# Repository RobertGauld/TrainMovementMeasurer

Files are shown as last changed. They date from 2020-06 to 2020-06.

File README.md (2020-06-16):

# Train Movement Measurer

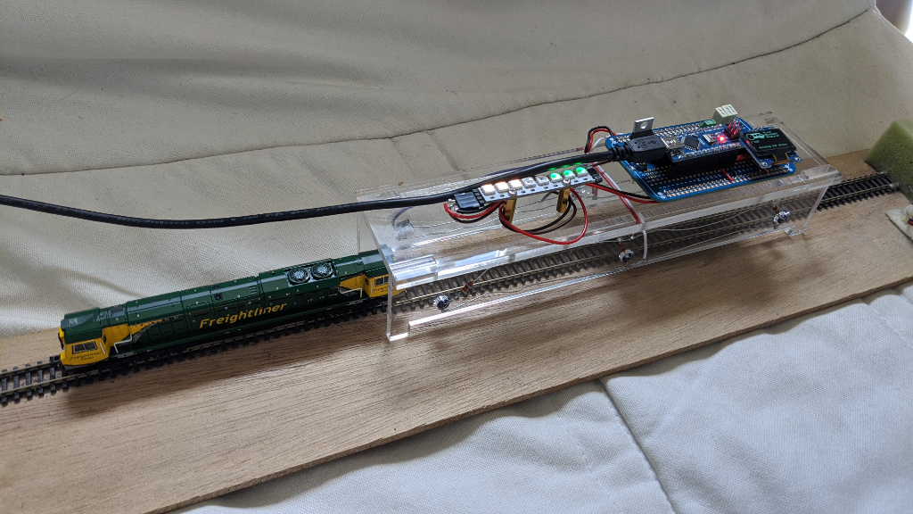
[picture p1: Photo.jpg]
Photo of completed project on my short test track


This is a project to to measure the scale speed and acceleration of a model train moving along a piece of straight track. I hope I've managed to document it such that someone just starting out with their [Arduino](https://www.arduino.cc/) adventure can follow along and create their own. If you're not a beginner you'll likely want to skim through rather than completely read this readme. The timings required can be made either by using three gates (detecting a train being a specific spot) or four blocks (detecting a train being in a specific part of the track). You can choose to only measure speed, in which case you need one less detector.

[Why?](#why)\
[The Physics & Maths](#the-physics-maths)\
[The Electronics & Tunnel](#the-electronics-tunnel)\
[Options](#options)

---

## Why?

By measuring the scale speed of a train you're able to more easily speed match across a fleet of [DCC](https://wikipedia.org/wiki/Digital_Command_Control "Digital Command Control on Wikipedia") equipped locomotives, or learn what a realistic running speed looks like. By also measuring acceleration you're able to automate the speed matching (if you're feeling adventurous) by only paying attention to readings once the train has clearly reached the desired speed step or learn how not to make your passengers spill their coffee.

## The Physics & Maths

We're going to assume that the track is a 20cm long straight length (curves are possible you just need to be careful with measuring how far the train travels between different triggers - the maths is then the same). Physicists normally love simplifying things down to spheres in a vacuum, however for us it's simpler to consider our train to be a solid cube travelling along a straight line (our track). The fact the front of our train isn't exactly a cube doesn't matter as assuming the detectors are all the same then they will be triggered when the same part of the train is at the spot we care about.

As we learnt and school speed is calculated by dividing distance travelled by time taken.\
_s = d ÷ t_\
To keep things simple we'll stick to metric so we end up with a measurement in m/s (meters per second). Since we know the distance between our triggers it's as simple is timing how long elapses between two triggers being triggered.
In the same way as speed measures the rate at which distance changes acceleration measures the rate at which speed changes, since we're working in metric this is in meters per second per second or m/s² (in the following formula Δ represents the change in a value).\
_a = Δs ÷ t_\
At this point we can do some conversions to get from m/s and m/s² into something a bit more meaningful:
* To get Km/h or Km/h/s multiply by 3.6 × scale
* To get mph or mph/s multiply by 2.236936 × scale

Now we now the basics, let's discover how to use three detectors to measure three speeds and one acceleration:\
d₁ is the distance between the first two triggers.\
d₂ is the distance between the last two triggers.\
d is the total distance (_d₁ + d₂_).\
t₁ is the time between the first two triggers.\
t₂ is the time between the last two triggers.\
t is the total time (_t₁ + t₂_).\
s₁ is the speed between the first two triggers.\
s₂ is the speed between the last two triggers.\
s is the speed between the first and last detector.\
a is the acceleration between the first and last  detector.

From the above we can easily calculate our speeds using:\
_s₁ = d₁ ÷ t₁_\
_s₂ = d₂ ÷ t₂_\
_s = d ÷ t_\
From here we have to understand that if the train is accelerating at a constant rate (which we're going to assume it is to keep things simple) then the speeds s₁ and s₂ occur at the times ½t₁ and ½t₂ (that is to say half way through each gap between detectors). We can therefore calculate the speed change and acceleration using:\
_Δs = s₂ - s₁_\
_a = Δs ÷ ½t_



There are two methods of measuring the time, depending on which style of train detection makes the most sense for your use case. I'll only describe the measurements for a train moving left to right but the code can also handle a train running right to left.\
Either we can setup three gates to detect when the train is a particular point of the track. Timer 1 is started when gate 0 is triggered and stopped when gate 1 is triggered. Timer 2 is started when gate 1 in triggered and stopped when gate 2 is triggered.\
Or we can setup four blocks of track to detect when a train is present in them (we only actually care about the length of two of them). Timer 1 is started when track 1 becomes occupied and stopped when track 2 becomes occupied. Timer 2 is started when track 2 is occupied and stopped when track 3 is occupied.
If you're only interested in measuring speed the comments in the code give you various options.

## The Electronics & Tunnel

The electronics are rather simple an Arduino provides the brains whilst an OLED display and NeoPixel LED stick let you know what's going on and how fast you're driving.
There are several options for detecting a train's position for the calculations, these are discussed in [Electronics/README.md](Electronics/README.md).

As you may be able to make out from the photo at the top I opted for using three light gates attached to a platic tunnel. A light gate is simply alight shining accorss the track into a detector, when the beam is broken we knoe the train has arrived at that point.
If you wish to use this method then see  [Tunnel/README.md](Tunnel/README.md).

## The Code

The code provides some test modes which can be used to troubleshoot the hardware, see the comments in the code for further details. The code may need some changes before you compile and upload it to the Arduino, follow the comments in the code file.

If you've built this exactly as I did you should only need to change one line (which tells the Arduino what scale to use). If you've kept the electronics the same but changed how far apart the light gates are you'll need to make 2 more changes. There are some other things you can tweak in the code such as how long the results are displayed on the screen for. Depending on your display you may need to make some more changes (probably the I2C address). You can also easily change the number of LEDs in the strip should for example you want to use a semi circle or longer stick with more LEDs - in which case you'll want to change the list of colours and what speeds they light for the LEDs.

The code goes through a number of steps when the Arduino receives power:
1. **Setup** - The Arduino gets itself and he screen up and going.
2. **Check** - That the sensors are clear, if not you'll get an error and the display and LEDs will be used to show you which sensors are clear/blocked.
3. **Wait for and time a train**:
    - Using gates:
       1. Wait for the light gate at either end to be blocked - We save when this happened, since we know what direction the train is travelling in we keep track of what the exiting light gate will be too. The LEDs are used to show the direction of travel and that the first time has been saved. The display is updated to show that a train is being timed.
       2. Wait for the middle light gate to be blocked - We save when this happened. The LEDs are used to show that this time has been saved. Skipped if measuring speed only.
       3. Wait for the final light gate to be blocked - We save when this happened. The LEDs are used to show that this time has been saved. We now have gathered all the data we need.
   - Using track occupancy:
       1. Wait for track 1 or 2 to become occupied - We save when this happened, since we now know the direction the train is travelling in we keep track of what the next and final track section will be (either [2 then 3] or [1 then 0]). The LEDs are used to show thw direction of travel and that the first time has been saved. The display is updated to show that a train is being timed.
       2. Wait for the other of track 1 or 2 to become occupied - We save when this happened. The LEDs are used to show that this time has been saved. Skipped if measuring speed only.
       3. Wait for either track 0 or 3 (as appropriate for the train's direction) to become occupied - We save when this happened. The LEDs are used to show that this time has been saved. We now have gathered all the data we need.
4. **Calculate** - We now use the time differences to calculate two speeds and an acceleration (or just the speed). These are then scaled and displayed on the display. The LEDs now show a bar of varying colours - the more LEDs the faster the scale speed. All the calculated values are output to the serial port too (see [SERIAL_PORT.md](SERIAL_PORT.md)).
5. **Wait** - After the configurable time delay (defaults to 15 seconds) we start checking that the train is completly left the area we're watching, when it has we go back to step 2.

## Options

### Gates Without the Light Beam

The only function which the light gates serve is to detect when the train is at specific spots on the track. This could alternativly be achieved in a number of different ways e.g. a button operated by a person or the train's wheels. You will need to make your own adjustments to the circuitry (see [Electronics/LightGates.md](Electronics/LightGates.md)). In addition you'll need to make the following changes in the code:
* Make sure that you configure TRIGGER_PINS to contain the Arduino pins connected to your detectors
* Remove/comment the "#define GATE_LED_PIN" line
* Ensure you set TRIGGER_DETECT correctly

### Track Occupancy Detection

There are a number of ways in which block detection work on a model railway, as such the interfacing between this project and the many available systems will vary. For this reason the electronics are left to the user to design (see [Electronics/Blocks.md](Electronics/Blocks.md)). In addition you'll need to make the following changes in the code:
* Make sure that you configure TRIGGER_PINS to contain the Arduino pins connected to your detectors
* Remove/comment the "#define GATE_LED_PIN" line
* Ensure you set TRIGGER_DETECT correctly
* Make sure that "#define TRIGGER_BLOCKS" is present

### Measure Speed Only

With the current code this is easily achieved by:
* Changing "#undef VELOCITY_ONLY" to "#define VELOCITY_ONLY"
* Making sure your detectors are numbered as the comments in the code describe

### Change the Logo

See [Logos/README.md](Logos/README.md).

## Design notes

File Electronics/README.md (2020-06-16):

# Train Movement Measurer - The Electronics

The heart of the project is an Arduino Nano where our code runs, this can be powered by the onboard USB or through the screw terminal which connects to the Arduino's Vin (accepting 7-12V DC, this circuit requires upto 500mA). It uses an OLED display (connected using I2C) and an optional strip of WS2812 LEDs for output (connected to wires soldered to the breadboard).

There are a number of options for detecting trains:
- [Light Gates](LightGates.md) - Three IR LEDs shine accross the track into three IR detectors. When the train breaks the beam we know it's at that spot. The third can be omitted if you're only measuring speed.
- [Gates](Gates.md) - Three detectors allow us to know when a train is at speific spots on the track. The third can be omitted if you're only measuring speed.
- [Block Occupancy](Blocks.md) - Four sections of track are fitted with train on track detectors. When the train enters/leaves each block we know how far it travelled.

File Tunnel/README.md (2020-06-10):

# Train Movement Measurer - The Tunnel

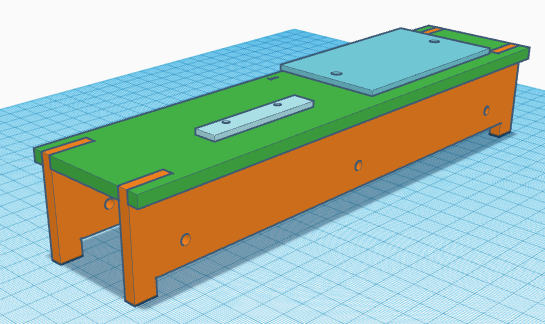
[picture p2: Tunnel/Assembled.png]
Assembled


To hold the light gates a fixed distance apart I had some acrylic LASER cut, in order to make sure it fit together first time I actually used some 3D printing CAD software to create the parts. As a result you have the option of using either of these as a starting point for your tunnel.
The tunnel is designed to take threaded inserts to hold the stand-offs for the breadboard and LED strip. It's also designed with rectangular holes to allow for the routing of wire. In my first build these proved tight but manageable so you may want to increase their length.
All that matters is that the LED and detector of each light gate are in a straight line from each other (preferably horizontal and perpendicular to the track) and are a known fixed distance apart. You could for example choose to have the detectors and circuitry hidden in a station waiting room and the LEDs disguised as relay cabinets should you wish.

## LASER Cutting

I'd previously used [RazorLAB](https://www.razorlab.online/) for some LASER cutting so took their template (no longer available) and added in the parts - [LASER.svg](LASER.svg).
It should be noted that they cut from standard sizes of acrylic and this design uses the middle size (with wastage). It could be shrunk to a shorter tunnel in exchange for fitting on a smaller size and saving money at the loss of accuracy. I've not done that maths but suspect for smaller than OO 5cm (rather than 10cm) spacing of the light gates would suffice. Alternatively the dead space could be used for another project or the experiment this this technology. The slots are designed so that it will fit together when cut from 5mm thick material, you could shrink to using 3mm thickness but would end up with the LEDs protruding more on the inside so watch your clearance.
You should also note that they've been designed for n gauge, for a different scale you'll likely want to change the height of the sides and width of the top to ensure appropriate clearance for your trains.
You should also ensure that the holes are the right size for your threaded inserts and spacing for your breadboard and LED strip.

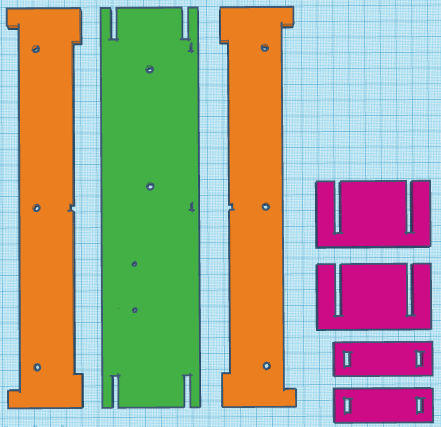
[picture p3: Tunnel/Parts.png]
Parts


The tunnel is designed in 3 parts (well 2 with one duplicated) and some parts to help keep it square during construction (in purple).
The green top is designed to hold the breadboard, LED stick and keep the sides in place. It has holes for threaded inserts and for wires to pass through.
The orange sides are identical and have two large notches at the top for aligning with the top, a large cut-out along the bottom to allow them to straddle point work, circular holes for LEDs/detectors and a rectangular hole for the routing of wires.

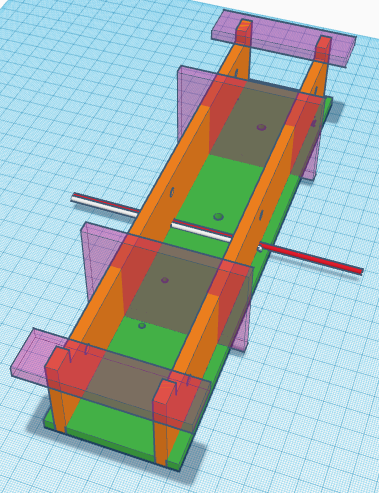
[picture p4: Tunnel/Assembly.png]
Assembly


As can be seen the purple supports will hold the sides square whilst the sides are glued to the top. The holes for the wire are quite tight so it's best to route two wires before glueing.
1. Insert the threaded inserts into the top.
2. Press the sides and top together, ensuring correct orientation.
3. Route the two wires:
    * White (colour doesn't actually matter but I'll be referring to it as white in [the electronics readme](../Electronics/README.md)) from the top, through the side, along the top inside the tunnel and out the other side.
    * Red (colour doesn't actually matter but I'll be referring to it as red in [the electronics readme](../Electronics/README.md)) from one side to the other.
4. Apply glue to the joints between the sides and top, ensuring not to accidentally glue the wires or purple supports.
5. Once the glue has sufficiently set remove the purple supports and glue and bits you had to skip over.

## 3D Printing

As mentioned above this STL file is a by-product of how I designed and test fitted the parts for LASER cutting and as such should be used at your risk.

I'm aware that the parts are larger than a typical build space it could be shrunk to a shorter tunnel in exchange for fitting on a smaller size and saving money at the loss of accuracy. I've not done that maths but suspect for smaller than OO 5cm (rather than 10cm) spacing of the light gates would suffice.
You should also note that they've been designed for n gauge, for a different scale you'll likely want to change the height of the sides and width of the top to ensure appropriate clearance for your trains.
You should also ensure that the holes are the right size for your threaded inserts and spacing for your breadboard and LED strip.

I encourage a contribution from anyone who'd like to take this STL and make a decent version for inclusion here.
[Print.stl](Print.stl)

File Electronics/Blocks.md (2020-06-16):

# Train Movement Measurer - The Electronics (Block Variation)

The heart of the project is an Arduino Nano where our code runs, this can be powered by the onboard USB or through the screw terminal (J4) which connects to the Arduino's Vin (accepting 7-12V DC, this circuit requires upto 500mA). It uses an OLED display (connected using I2C to J1) and an optional strip of WS2812 LEDs for output (connected to wires soldered to the breadboard, J3 in the schematic).

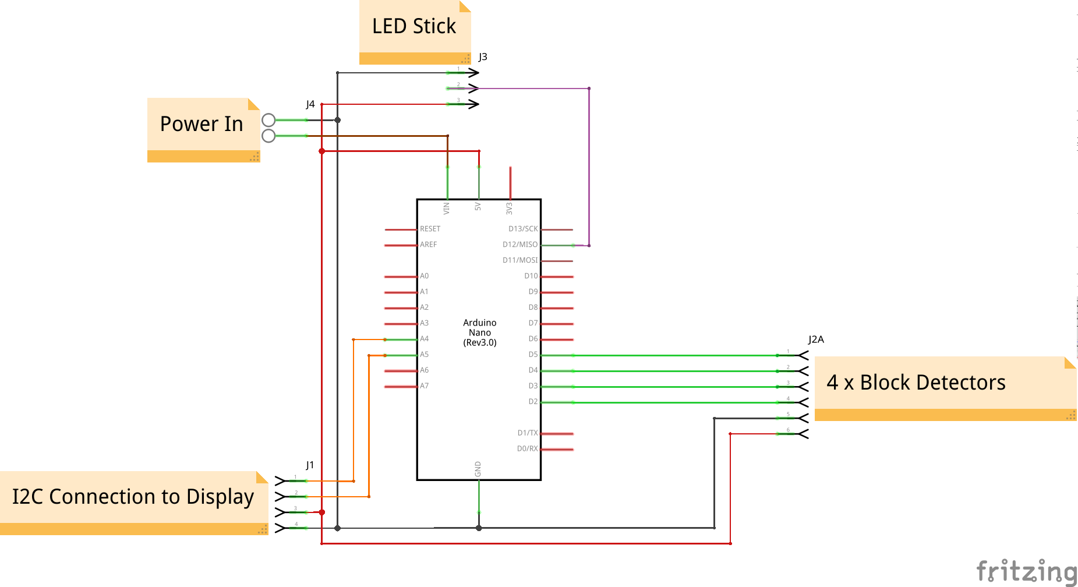
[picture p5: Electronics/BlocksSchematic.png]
Circuit Schematic


Input for timing trains comes from four block occupancy detectors which detect when a train is in a section of the track. Since the interfacing electronics is dependent on your detection method you'll need to design this part for yourself. Try to keep to using Arduino pins 6-2 for blocks 0-4.

## Parts List

* 1 x Half size solderable breadboard
* 1 x Arduino Nano
* 2 x 15x1 Female PCB headers (for Arduino Nano)
* 1 x 4x1 Female PCB header (for display)
* 1 x I2C OLED 128x64 or 128x32
* 1 x NeoPixel Stick (or other shape, at least 8 LEDs)
* 1 x 2 way 2.54mm screw terminal (if external power required)

## Assembly

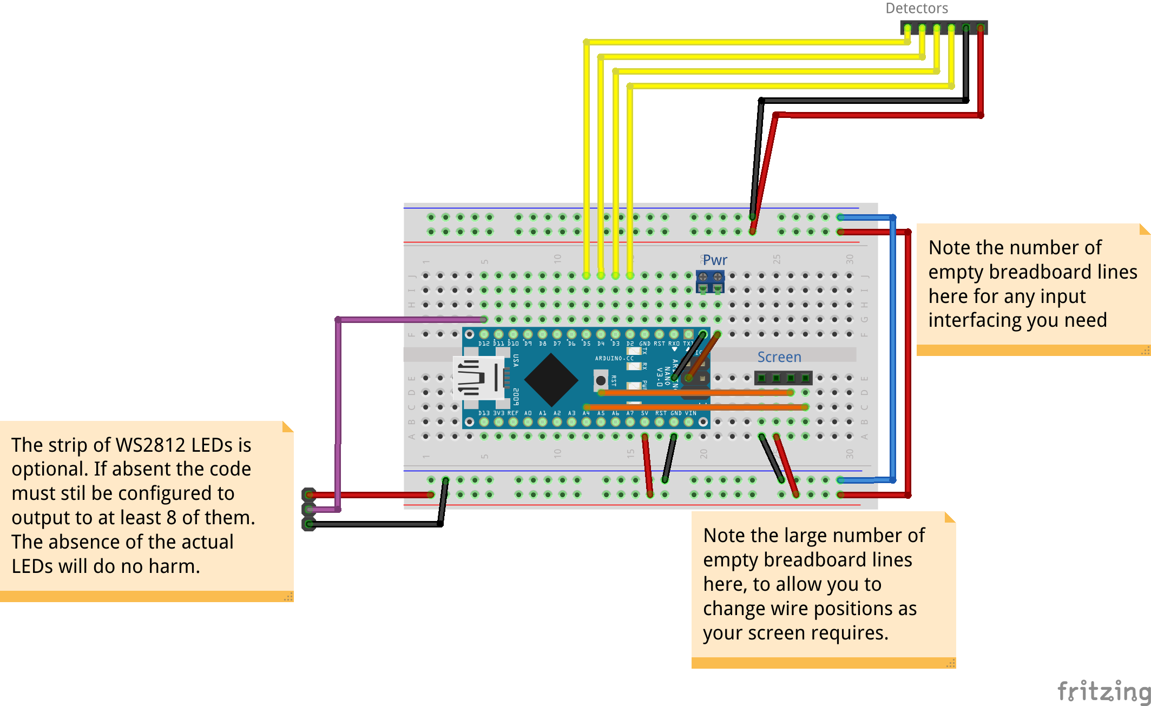
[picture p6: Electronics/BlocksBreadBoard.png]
Breadboard Layout


As always with assembling electronics it's best to go in height order (shortest components to tallest). Note that the wires on the Arduino are actually wired underneath, their just shown there to make where to put them visible. When attaching the headers solder only one pin first then make sure it's sitting square to the board before soldering the rest.

### The breadboard

Start by aligning your solder breadboard as shown by the main board (A1 bottom left and J30 top right).
1. Solder wires between the following pairs of holes:
    * Both blue rails
    * Both red rails
    * A16 - Red rail
    * A18 - Blue rail
    * J4 - Blue rail
    * If you're fitting the power connector:
      * E18 - F20
      * E19 - F21
    * For the screen (note you may need to adjust these based on your screen's size and pinout):
      * C12 - C27
      * D13 - D26
      * A24 - Blue rail
      * A25 - Red rail
2. Solder the screw terminal (if fitting the power connector) to I20-I21
3. Solder the 4x1 header for the screen
4. Solder the 15x1 headers to B5-B19 and F5-F19

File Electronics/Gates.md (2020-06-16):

# Train Movement Measurer - The Electronics (Gate Variation)

The heart of the project is an Arduino Nano where our code runs, this can be powered by the onboard USB or through the screw terminal (J4) which connects to the Arduino's Vin (accepting 7-12V DC, this circuit requires upto 500mA). It uses an OLED display (connected using I2C to J1) and an optional strip of WS2812 LEDs for output (connected to wires soldered to the breadboard, J3 in the schematic).

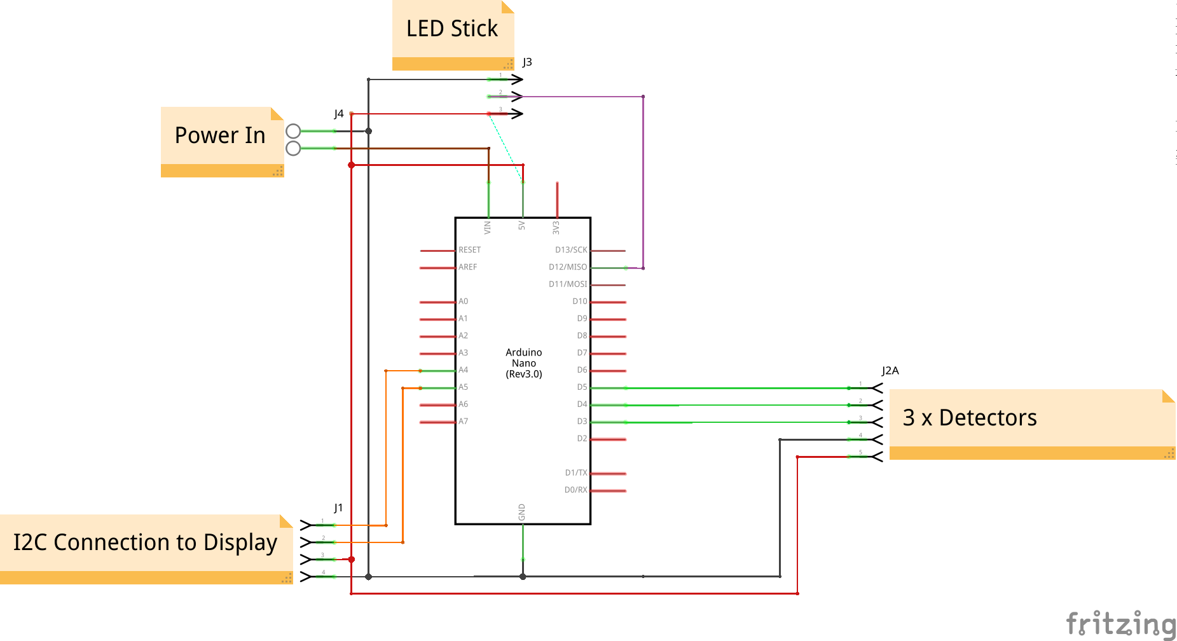
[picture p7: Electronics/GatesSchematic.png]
Circuit Schematic


Input for timing trains comes from three gates which are triggered when the train is at a specific spot of the track. Since the interfacing electronics is dependent on your detection method you'll need to design this part for yourself. Try to keep to using Arduino pins 5-3 for gates 0-2.

## Parts List

* 1 x Half size solderable breadboard
* 1 x Arduino Nano
* 2 x 15x1 Female PCB headers (for Arduino Nano)
* 1 x 4x1 Female PCB header (for display)
* 1 x I2C OLED 128x64 or 128x32
* 1 x NeoPixel Stick (or other shape, at least 8 LEDs)
* 1 x 2 way 2.54mm screw terminal (if external power required)

## Assembly

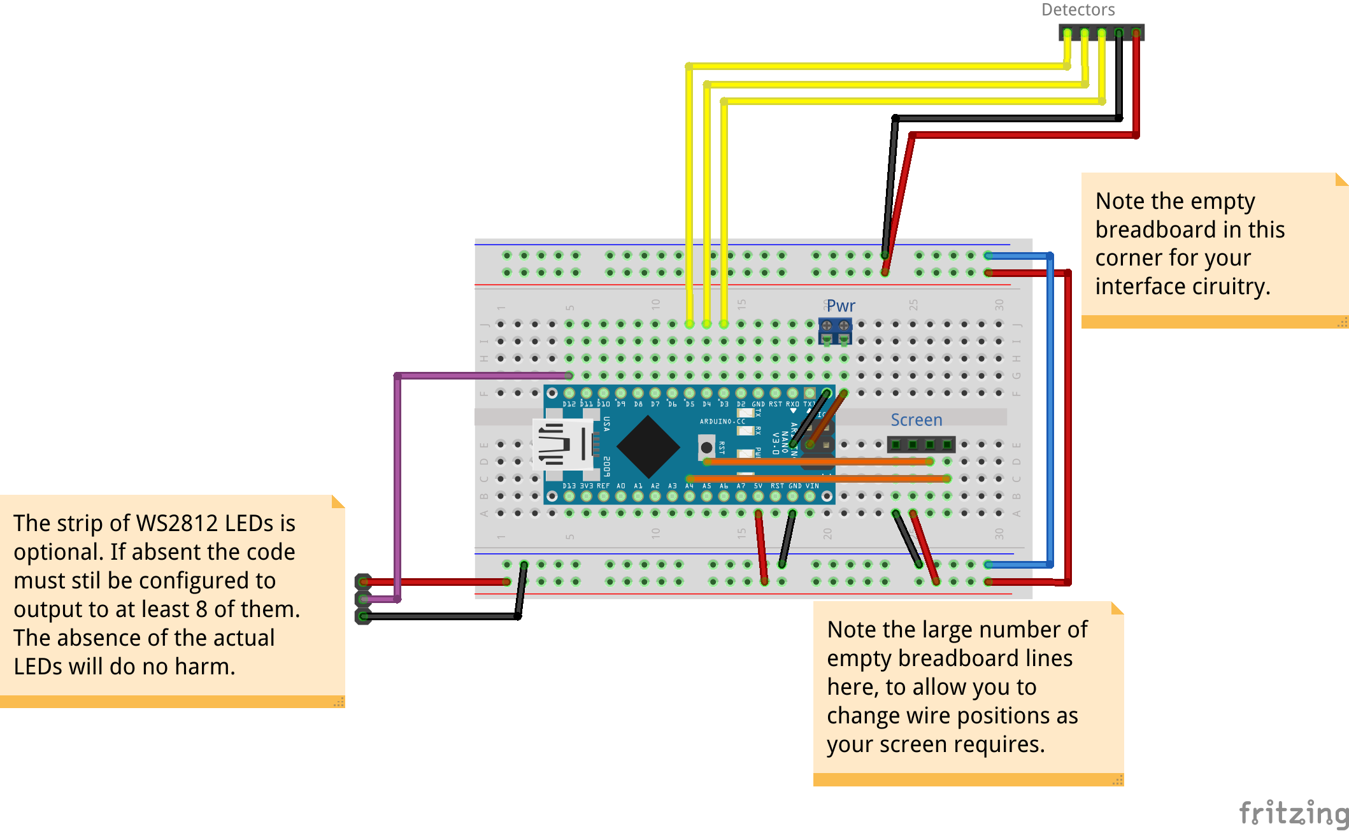
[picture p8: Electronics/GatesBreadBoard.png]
Breadboard Layout


As always with assembling electronics it's best to go in height order (shortest components to tallest). Note that the wires on the Arduino are actually wired underneath, their just shown there to make where to put them visible. When attaching the headers solder only one pin first then make sure it's sitting square to the board before soldering the rest.

### The breadboard

Start by aligning your solder breadboard as shown by the main board (A1 bottom left and J30 top right).
1. Solder wires between the following pairs of holes:
    * Both blue rails
    * Both red rails
    * A16 - Red rail
    * A18 - Blue rail
    * J4 - Blue rail
    * If you're fitting the power connector:
      * E18 - F20
      * E19 - F21
    * For the screen (note you may need to adjust these based on your screen's size and pinout):
      * C12 - C27
      * D13 - D26
      * A24 - Blue rail
      * A25 - Red rail
2. Solder the screw terminal (if fitting the power connector) to I20-I21
3. Solder the 4x1 header for the screen
4. Solder the 15x1 headers to B5-B19 and F5-F19

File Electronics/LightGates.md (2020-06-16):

# Train Movement Measurer - The Electronics (Light Gate Variation)

The heart of the project is an Arduino Nano where our code runs, this can be powered by the onboard USB or through the screw terminal (J4) which connects to the Arduino's Vin (accepting 7-12V DC, this circuit requires upto 500mA). It uses an OLED display (connected using I2C to J1) and an optional strip of WS2812 LEDs for output (connected to wires soldered to the breadboard, J3 in the schematic).

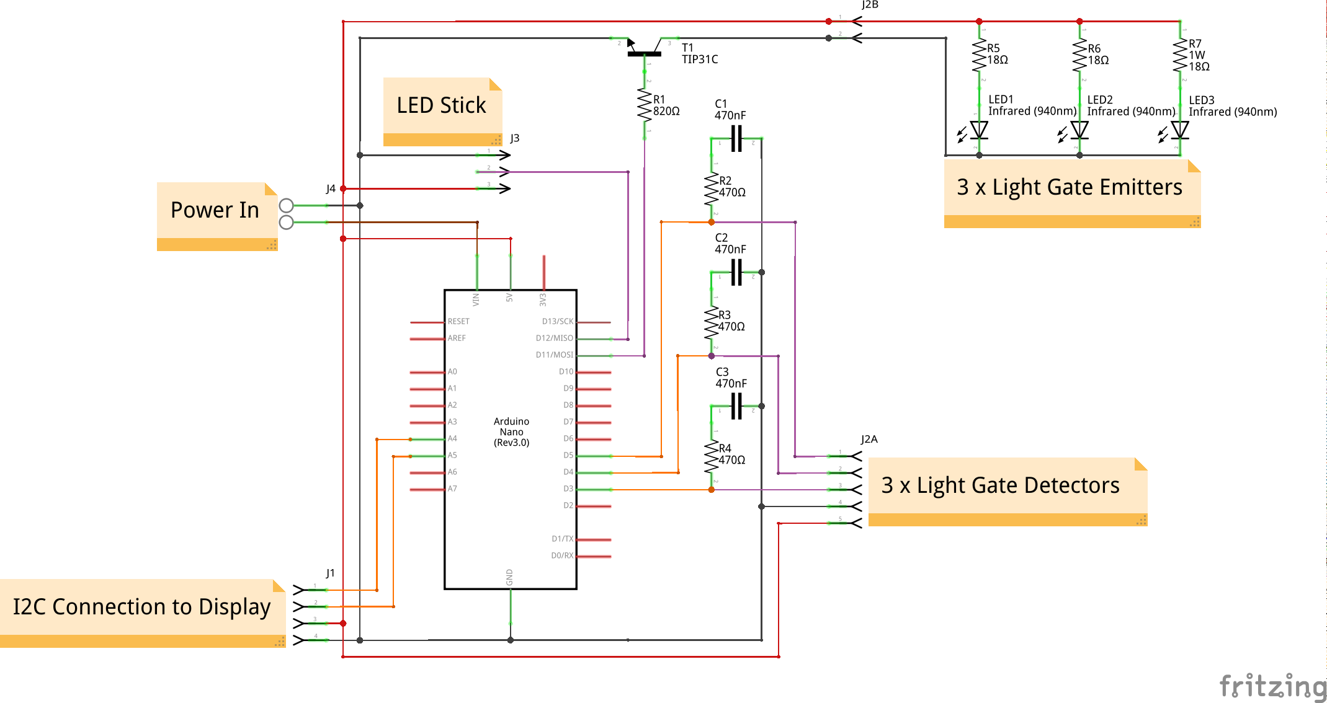
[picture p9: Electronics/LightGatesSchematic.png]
Circuit Schematic


Input for timing trains comes from three light gates using the IR LEDs and detectors. The LEDs are controlled via a transistor to allow them to be flashed at 38KHz. The detectors are connected to the Arduino via a simple RC filter to smooth out the occasional erroneous low reading.
The RC filters work by charging the capacitor whilst the detector's output is high, when the output goes low the capacitor discharges through the resistor keeping the signal to the Arduino high for around 0.15ms. Whilst this does introduce a delay in detection since it's the same delay at each gate and it's the difference we're interested in the delay doesn't matter for our purpose.

## Parts List

* 1 x Half size solderable breadboard
* 1 x Arduino Nano
* 2 x 15x1 Female PCB headers (for Arduino Nano)
* 1 x 4x1 Female PCB header (for display)
* 1 x I2C OLED 128x64 or 128x32
* 1 x NeoPixel Stick (or other shape, at least 8 LEDs)
* 1 x TIP31C NPN transistor (T1)
* 1 x 820Ω 0.6W resistor (R1)
* 3 x 18Ω 1W resistor (R5, R6, R7)
* 3 x 950nm IR LED (TSUS5202)
* 3 x 470Ω 0.6W resistor (R2, R3, R4)
* 3 X 470nF capacitor (C1, C2, C3)
* 3 x TSSP4038 IR receiver
* 1 x 2 way 2.54mm screw terminal (if external power required)

## Assembly

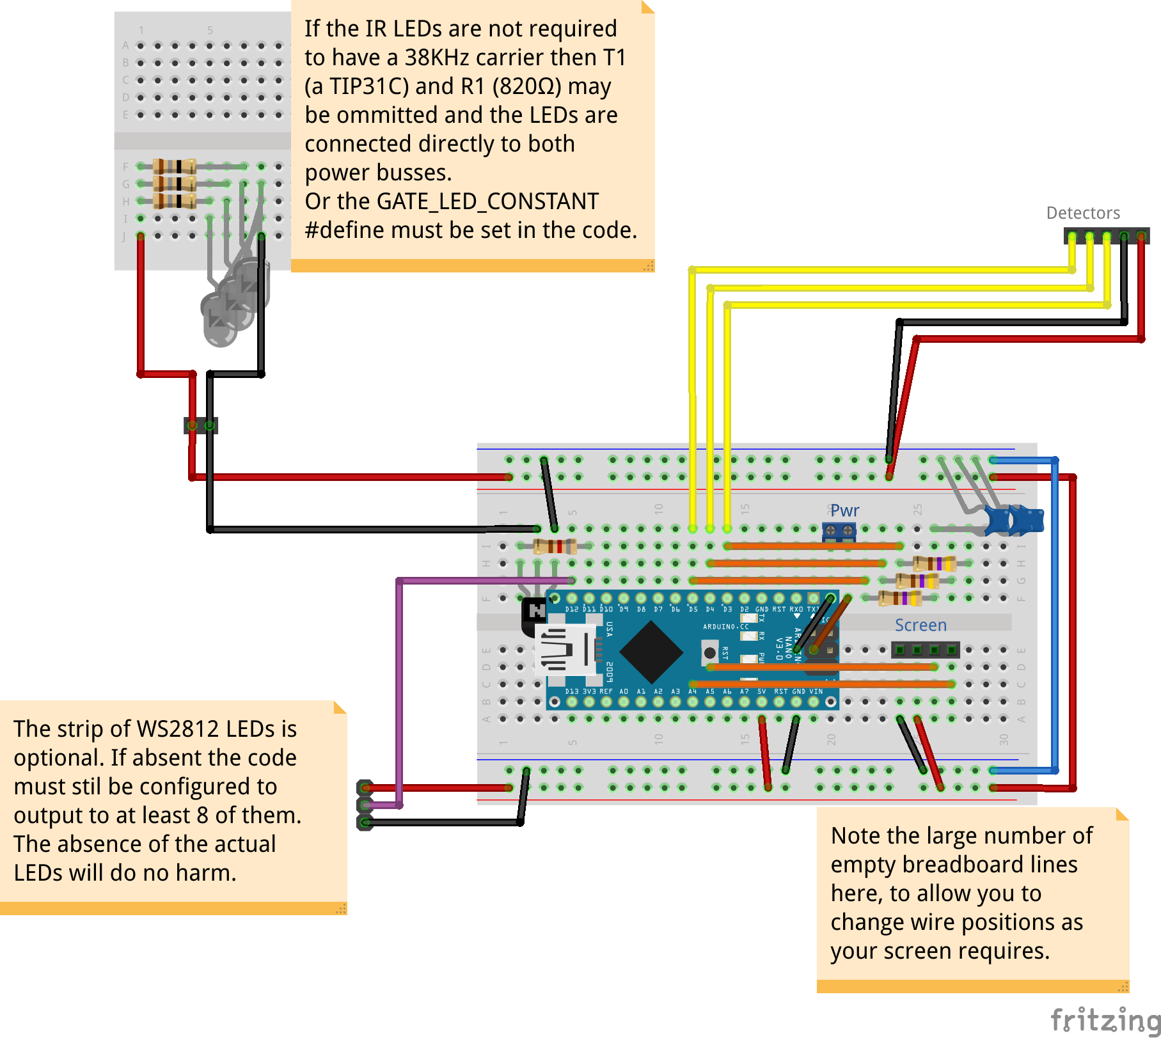
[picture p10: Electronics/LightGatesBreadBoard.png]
Breadboard Layout


As always with assembling electronics it's best to go in height order (shortest components to tallest). Note that the wires on the Arduino are actually wired underneath, their just shown there to make where to put them visible. When attaching the headers solder only one pin first then make sure it's sitting square to the board before soldering the rest.

### The breadboard

Start by aligning your solder breadboard as shown by the main board (A1 bottom left and J30 top right).
1. Solder wires between the following pairs of holes:
    * Both blue rails
    * Both red rails
    * A16 - Red rail
    * A18 - Blue rail
    * J4 - Blue rail
    * If you're fitting the power connector:
      * E18 - F20
      * E19 - F21
    * For the screen (note you may need to adjust these based on your screen's size and pinout):
      * C12 - C27
      * D13 - D26
      * A24 - Blue rail
      * A25 - Red rail
    * Be careful to allow enough space for the power connector if you're fitting it:
      * I14 - I24
      * H13 - H23
      * G12 - G22
2. Solder the resistors:
    * R1 (820Ω) between I2 and I6
    * R2 (470Ω) between F22 and F26
    * R3 (470Ω) between G23 and G27
    * R4 (470Ω) between H24 and H28
3. Solder the capacitors:
    * C1 (470nF) between J26 and blue rail
    * C2 (470nF) between J27 and blue rail
    * C3 (470nF) between J28 and blue rail
4. Solder the transistor making sure that the metallic side way from the Arduino.
5. Solder the screw terminal (if fitting the power connector) to I20-I21
6. Solder the 4x1 header for the screen
7. Solder the 15x1 headers to B5-B19 and F5-F19

### The light gate LEDs

Assuming that you've built the tunnel as described in [the tunnel readme](../Tunnel/README.md), if not then you'll need to adjust these instructions to suit what you have. Whilst you can't check if the LED is lit by looking at it the camera in your smart phone can. You should be working on the side which is furthest from the wire hole on the top piece and closest to the holes for the LED strip.

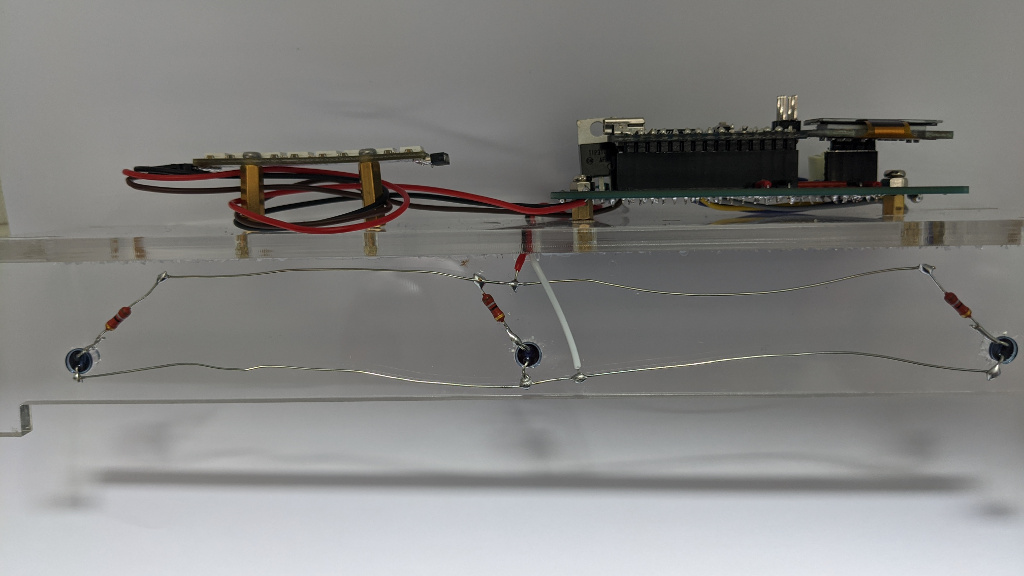
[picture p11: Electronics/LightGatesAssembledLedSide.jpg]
Photo of assembled LED side


1. Attach R5 to the positive lead of LED1 (electrically the negative side works too). Repeat for R6 to LED2 and R7 to LED3. You'll probably need to trim the leads before hand to make the LED + resistor combinations fit.
2. Temporarily mount one of the side LEDs into it's hole with the resistor towards the top and the other lead towards the bottom.
3. Solder one end of some bare wire to the resistor, unroll it al the way to the other end of the side and trim. Do the same for the negative lead.
4. Now mount the LED at the other end and solder to the bare wires, these should now be trimmed for a neat finish.
5. Now mount the middle LED and solder to the bare wires.
6. Attach the red wire (colour doesn't actually matter but I'll be referring to it as red later) to the positive bare wire it should route to the other side of the tunnel.
7. Attach the white wire (colour doesn't actually matter but I'll be referring to it as white later), to the negative bare wire it should route to the top of the tunnel.
8. The LEDs should be a snug fit into the holes but a dab of glue applied to each will keep them where they are.

### The light gate detectors

Assuming that you've built the tunnel as described in [the tunnel readme](../Tunnel/README.md), if not then you'll need to adjust these instructions to suit what you have. You should be working on the side which is closest to the wire hole on the top piece and furthest from the holes for the LED strip. Make sure to understand which pins of the detector are +ve, gnd and signal.

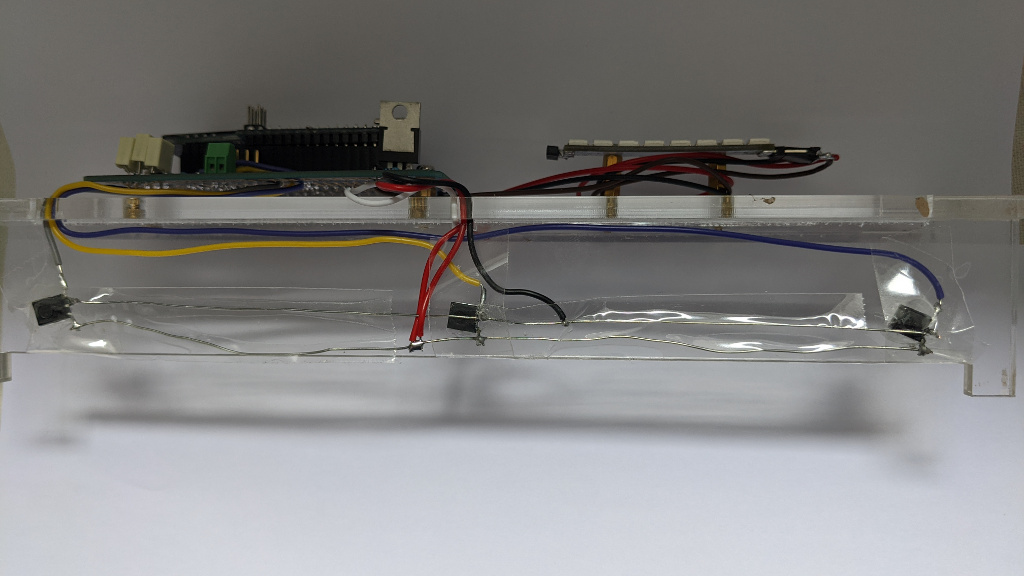
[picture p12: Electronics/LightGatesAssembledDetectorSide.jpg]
Photo of assembled detector side


1. Using the bare wire "trick" used for the LEDs attach all the positive and ground pins together.
2. The signal pins should be attached to different coloured wires and routed to the top of the tunnel.
3. Attach the black wire (colour doesn't actually matter but I'll be referring to it as black later) to the ground bare wire it should route to the top of the tunnel.
4. Attach the red wire from the top of the tunnel (colour doesn't actually matter but I'll be referring to it as red later) to the positive bare wire.
5. Attach the red wire from the other side of the tunnel to the positive bare wire.
6. I had trouble securing these with glue and so their taped in place on mine.

### Connecting the LEDs and detectors

If you have followed the instructions above you'll have a tunnel with a red, a black, a white and three different coloured wires appearing out the top.

1. Solder the red wire (or whatever goes to the positive of both sides) to a red rail on the breadboard.
2. Solder the black wire (or whatever goes to the ground of the detector side) to a blue rail on the breadboard.
3. Solder the white wire (or whatever goes to the negative of the LED side) to J3.
4. Solder the signal wire for the detector furthest from the breadboard to J12.
5. Solder the signal wire for the middle detector to J13.
6. Solder the signal wire for the detector closest to the breadboard to J14.

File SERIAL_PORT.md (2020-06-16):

# Train Movement Measurer - The Serial Port

The serial port runs at 9600 baud, 8 data bits, no parity, 1 stop bit.

## Input

No input is expected or checked for.

## Output

Each output line follows the format ```<TYPE>: <MESSAGE>```.

### READY
Denotes that the unit is setup and ready for use, lists the configuration of the unit in a space delimited list of ```<DESCRIPTION>:<VALUE>``` fields.

### ERROR
An error condition has occurred, see the message for more details.
e.g. if something is in the tunnel on start up

### STATUS
Mainly for debugging, the message cycles between:
* Waiting for train.
* Timing train.
* Calculating.

Additionally when a test mode is used you'll get something like "Testing triggers.".

### VA_DATA
A list of the configured, measured and calculated data, it's space delimited and units are included, in order the fields are:
* scale (e.g. 1:148)
* distance of the first section (millimetres)
* distance of the second section (millimetres)
* total time (milliseconds)
* time taken in first section (milliseconds)
* time taken in second section (milliseconds)
* velocity over whole distance (meters per second)
* velocity over first section (meters per second)
* velocity over second section (meters per second)
* acceleration (meters per second per second)
* scale velocity (kilometres per hour)
* scale acceleration (kilometres per hour per second)
* scale velocity (miles per hour)
* scale acceleration (miles per hour per second)

Where first and second are determined by the order the train triggered them not their order on the track.

### V_DATA
A list of the configured, measured and calculated data, it's space delimited and units are included, in order the fields are:
* scale (e.g. 1:148)
* distance travelled (millimetres)
* time taken (milliseconds)
* velocity (meters per second)
* scale velocity (kilometres per hour)
* scale velocity (miles per hour)

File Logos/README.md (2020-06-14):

# Alternative Logos

Here's a list of logos that other people have created for their version.

It's easy enough to create your own logo:
1. Open your prefered image editor and create a new image no more than 64 pixels wide and 29 pixels high, sticking to black and white (unless you used a colour display for this project).
2. Create your logo.
3. Save it as a bitmap (.bmp file).
4. Go to [https://javl.github.io/image2cpp/](https://javl.github.io/image2cpp/) and convert your image into plain bytes. A white pixel will be turned on and a black tuned off on the display so you may want to invert the image colours.
5. You can now load the logo into the Arduino sketch to check how it looks:
   1. Search the sketch for the line "// Defines and bitmap data for the logo".
   2. Copy-Paste your plain bytes from the conversion site into the value of the logoBmp variable.
   3. Make sure that LOGO_HEIGHT and LOGO_WIDTH are set correctly.
   4. Upload and run the sketch.
6. If you're happy then please share the bitmap and sketch lines as below for others to enjoy and use.

---

## A speedometer and end of a DMU combined - The Provided Logo
```
#define LOGO_HEIGHT 29
#define LOGO_WIDTH  64
const PROGMEM unsigned char logoBmp[] = {
  0x00, 0x00, 0x00, 0x00, 0x00, 0x00, 0x00, 0x00, 0x00, 0x00, 0x00, 0x00, 0x00, 0x00, 0x00, 0x00, 
  0x00, 0x3f, 0x80, 0x00, 0x00, 0x00, 0x00, 0x00, 0x00, 0xe4, 0xff, 0xff, 0xff, 0xff, 0xc0, 0x00, 
  0x03, 0x04, 0x1f, 0xff, 0xff, 0xff, 0xf0, 0x00, 0x06, 0x04, 0x0f, 0xff, 0xff, 0xff, 0xfc, 0x00, 
  0x0c, 0x00, 0x07, 0xff, 0xff, 0xff, 0xff, 0x00, 0x1a, 0x00, 0x0b, 0x30, 0x06, 0x00, 0x63, 0x80, 
  0x11, 0x00, 0x11, 0x30, 0x06, 0x00, 0x61, 0xc0, 0x20, 0x00, 0x00, 0xb0, 0x06, 0x00, 0x60, 0xe0, 
  0x20, 0x00, 0x40, 0xb0, 0x06, 0x00, 0x60, 0x70, 0x60, 0x00, 0x80, 0xf0, 0x06, 0x00, 0x60, 0x38, 
  0x40, 0x01, 0x00, 0x70, 0x06, 0x00, 0x60, 0x1c, 0x40, 0x02, 0x00, 0x70, 0x06, 0x00, 0x60, 0x0e, 
  0x78, 0x04, 0x03, 0xf0, 0x06, 0x00, 0x60, 0x0f, 0x40, 0x00, 0x00, 0x7f, 0xff, 0xff, 0xff, 0xff, 
  0x40, 0x00, 0x00, 0x7f, 0xff, 0xff, 0xff, 0xff, 0x60, 0x00, 0x00, 0xff, 0xff, 0xff, 0xff, 0xfe, 
  0x20, 0x00, 0x00, 0xff, 0xff, 0xff, 0xff, 0xfe, 0x20, 0x00, 0x00, 0xff, 0xff, 0xff, 0xff, 0xf8, 
  0x11, 0x00, 0x11, 0xff, 0xff, 0xff, 0xff, 0xf0, 0x1a, 0x00, 0x0b, 0xff, 0xff, 0xff, 0xff, 0xf0, 
  0x0c, 0x00, 0x06, 0x00, 0x00, 0x00, 0x00, 0x00, 0x06, 0x00, 0x0c, 0x00, 0x00, 0x07, 0xff, 0x80, 
  0x03, 0x00, 0x18, 0x00, 0x00, 0x03, 0xcf, 0x00, 0x00, 0xe0, 0xe0, 0x00, 0x00, 0x01, 0x86, 0x00, 
  0x00, 0x3f, 0x80, 0x00, 0x00, 0x00, 0x00, 0x00, 0x00, 0x00, 0x00, 0x00, 0x00, 0x00, 0x00, 0x00, 
  0x00, 0x00, 0x00, 0x00, 0x00, 0x00, 0x00, 0x00
};
```

---

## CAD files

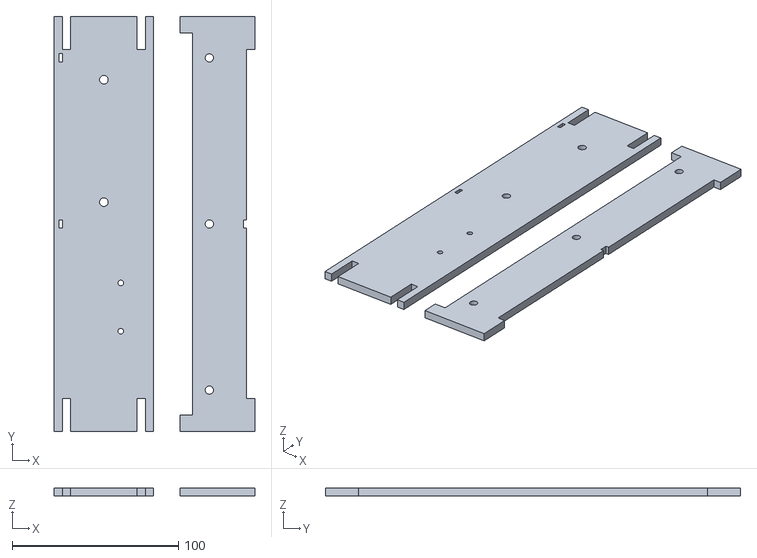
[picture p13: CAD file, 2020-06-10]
Tunnel/Print.stl
121.0 x 250.0 x 5.00

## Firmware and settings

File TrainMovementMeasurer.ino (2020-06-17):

/*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
 * THIS SOFTWARE IS PROVIDED BY THE COPYRIGHT HOLDERS AND CONTRIBUTORS "AS IS" AND ANY
 * EXPRESS OR IMPLIED WARRANTIES, INCLUDING, BUT NOT LIMITED TO, THE IMPLIED WARRANTIES
 * OF MERCHANTABILITY AND FITNESS FOR A PARTICULAR PURPOSE ARE DISCLAIMED. IN NO EVENT
 * SHALL THE COPYRIGHT HOLDER OR CONTRIBUTORS BE LIABLE FOR ANY DIRECT, INDIRECT, INCIDENTAL,
 * SPECIAL, EXEMPLARY, OR CONSEQUENTIAL DAMAGES (INCLUDING, BUT NOT LIMITED TO, PROCUREMENT
 * OF SUBSTITUTE GOODS OR SERVICES; LOSS OF USE, DATA, OR PROFITS; OR BUSINESS INTERRUPTION)
 * HOWEVER CAUSED AND ON ANY THEORY OF LIABILITY, WHETHER IN CONTRACT, STRICT LIABILITY,
 * OR TORT (INCLUDING NEGLIGENCE OR OTHERWISE) ARISING IN ANY WAY OUT OF THE USE OF THIS
 * SOFTWARE, EVEN IF ADVISED OF THE POSSIBILITY OF SUCH DAMAGE.
 */

/*
 * Train Movement Measurer
 * Uses three light gates to calculate the scale velocity and acceleration for a model train.
 * Maximum current draw is 0.5A (assuming a stick of 8 LEDs).
 * Full documentation for getting started with ths project can be found at
 * https://github.com/robertgauld/TrainMovementMeasurer
 * 
 * You should only need to make changes in the "User" defines section below, if you also model
 * in British N gauge and have built the tunnel and electronics as described then you shouldn't
 * need to make any changes. If things don't quite work for you search the code for "#define TEST_"
 * and you'll find some test modes which may help you trouble shoot. Simply uncomment the relevant
 * #define line and reload the program to the Arduino.
 * 
 * 
 * Three light gates placed along a track allow for two velocities to be measured. Knowing these two
 * velocities and time between them an acceleration can also be calculated, this is then scaled and displayed
 * on the screen.
 *                   |    <- DISTANCE_0 ->    |    <- DISTANCE_1 ->    |
 *          =========|========================|========================|========
 *                 Gate 0                   Gate 1                   Gate 2
 * 
 * You can use two light gates placed along a track you measure just velocity.
 * Set DISTANCE_1 to zero if you wish to do this.
 *                   |                 <- DISTANCE_0 ->               |
 *          =========|================================================|=========
 *                 Gate 0                                           Gate 1
 * 
 * 
 * Alternativly four occupancy blocks can be used to measure the two velocities and accelerations.
 *                   |    <- DISTANCE_0 ->    |    <- DISTANCE_1 ->    |
 *          =========|========================|========================|========
 *           Block 0          Block 1                   Block 2          Block 3
 * Or three can measure speed only in either direction, over the same block.
 *                          |         <- DISTANCE_0 ->         |
 *          ================|==================================|================
 *              Block 0                    Block 1                   Block 2
 * Or two can measure speed only in either direction, with each block wirking in one direction only.
 *                   |    <- DISTANCE_0 ->    |    <- DISTANCE_1 ->    |
 *                   |  Speed measured ---->  |  <---- Speed measured  |
 *          =========|========================|========================|========
 *                            Block 0                   Block 1
 * 
 * 
 * After calculating the scale velocity and acceleration are displayed on the right had side of the screen
 * and output to the serial port. This information will remain on the screen for INTER_TRAIN_DELAY
 * milliseconds (originally 15000) or until the train has completly left the tunnel (whichever is longer).
 * 
 * A series of addressable LEDs can also be attached which will show:
 *   - During timing:
 *     ~ The state of the gates (first 3 LEDs) whilst waiting for or timing a train [Green is clear, Red is blocked].
 *     ~ The state of the captured times (last 3 LEDs) [Yellow is uncaptured, blue is captured].
 *     ~ The direction of the trains travel (last half of the middle for 0->1->2, first half for 2->1->0).
 *   - A velocity bar, controlled by velocityBarValues[].
 * 
 * The onboard LED has three states:
 *   - On - Running setup
 *   - Flashing (2Hz) - Terminal error
 *   - Off - Running normally
 */


#include <SPI.h>
#include <Wire.h>
#include <Adafruit_GFX.h>
#include <Adafruit_SSD1306.h>
#include <FastLED.h>


// User defines
#define DISTANCE_0    100           // Distance 0 (millimeters) from the above diagrams
#define DISTANCE_1    100           // Distance 1 (millimeters) from the above diagrams
#define SCALE         148           // Scale for calculating scale velocity/acceleration (1:SCALE)
#undef VELOCITY_ONLY                // Whether to measure only velocity (requires less triggers)


// Defines for triggers
const PROGMEM uint8_t TRIGGER_PINS[] = {5, 4, 3}; // Trigger pins
#define TRIGGER_COUNT    3          // The number of pins in the above list
#define TRIGGER_MODE     INPUT      // Trigger type (INPUT or INPUT_PULLUP)
#define TRIGGER_DETECT   HIGH       // State of the trigger when a train is detected (HIGH or LOW)
#define TRIGGER_GATES               // What sort of triggers you're using (TRIGGER_GATES or TRIGGER_BLOCKS)
#define INTER_TRAIN_DELAY  15000    // Display the train's measaurements for at least this long (milliseconds)


// Defines for light gates
// Comment out both these settings if you're not using light gates
#define GATE_LED_PIN  11            // Output pin for controlling the light gate LEDs
#define GATE_LED_RATE 0             // Rate at which to flash the light gate LEDs (Hz, 62-8000000, 0 = constantly on)


// Defines for LED stick
#define LEDS_BRIGHT   24            // How bright to have the LEDs (0 - 255)
#define LEDS_PIN      12            // Data pin for the LEDs
#define LEDS_COUNT    8             // Number of LEDs (must be at least 8)
                                    // be sure to adjust the velocity bars below too !!!
#undef LEDS_REVERSE                 // Reverse the direction of the LED numbering, such that 0 is on the right not the left
#define LEDS_TYPE     WS2812        // Type of LEDs
#define LEDS_ORDER    GRB           // Color order of LED data
CRGB leds[LEDS_COUNT];


// Defines for screen - you should only need to change SCREEN_WIDTH and/or SCREEN_HEIGHT
// It's intended that an ADAfruit OLED will be used - either 128x64 or 128x32 although 96x64 or 64x32 (not advised!) should work too.
#define SCREEN_WIDTH       128     // Height of screen in pixels (must be at least 64)
#define SCREEN_HEIGHT      64      // Width of screen in pixels (must be at least 32)
#define SCREEN_ROTATION    0       // Adjust the screen rotation in steps of 90deg (0 - 3), if rotating by 1 or 3 swap _WIDTH and _HEIGHT above
#define SCREEN_RESET_PIN   -1      // Reset pin (or -1 if sharing Arduino reset pin)
#define SCREEN_I2C_ADDRESS 0x3C    // Screen's I2C address (if using Adafruit's 128x64 then it's 0x3D)
#define SCREEN_CHAR_WIDTH  6       // Character height on OLED display
#define SCREEN_CHAR_HEIGHT 8       // Character height on OLED display


// Defines and bitmap data for the logo
#define LOGO_HEIGHT 29
#define LOGO_WIDTH  64
const PROGMEM unsigned char logoBmp[] = {
  0x00, 0x00, 0x00, 0x00, 0x00, 0x00, 0x00, 0x00, 0x00, 0x00, 0x00, 0x00, 0x00, 0x00, 0x00, 0x00, 
  0x00, 0x3f, 0x80, 0x00, 0x00, 0x00, 0x00, 0x00, 0x00, 0xe4, 0xff, 0xff, 0xff, 0xff, 0xc0, 0x00, 
  0x03, 0x04, 0x1f, 0xff, 0xff, 0xff, 0xf0, 0x00, 0x06, 0x04, 0x0f, 0xff, 0xff, 0xff, 0xfc, 0x00, 
  0x0c, 0x00, 0x07, 0xff, 0xff, 0xff, 0xff, 0x00, 0x1a, 0x00, 0x0b, 0x30, 0x06, 0x00, 0x63, 0x80, 
  0x11, 0x00, 0x11, 0x30, 0x06, 0x00, 0x61, 0xc0, 0x20, 0x00, 0x00, 0xb0, 0x06, 0x00, 0x60, 0xe0, 
  0x20, 0x00, 0x40, 0xb0, 0x06, 0x00, 0x60, 0x70, 0x60, 0x00, 0x80, 0xf0, 0x06, 0x00, 0x60, 0x38, 
  0x40, 0x01, 0x00, 0x70, 0x06, 0x00, 0x60, 0x1c, 0x40, 0x02, 0x00, 0x70, 0x06, 0x00, 0x60, 0x0e, 
  0x78, 0x04, 0x03, 0xf0, 0x06, 0x00, 0x60, 0x0f, 0x40, 0x00, 0x00, 0x7f, 0xff, 0xff, 0xff, 0xff, 
  0x40, 0x00, 0x00, 0x7f, 0xff, 0xff, 0xff, 0xff, 0x60, 0x00, 0x00, 0xff, 0xff, 0xff, 0xff, 0xfe, 
  0x20, 0x00, 0x00, 0xff, 0xff, 0xff, 0xff, 0xfe, 0x20, 0x00, 0x00, 0xff, 0xff, 0xff, 0xff, 0xf8, 
  0x11, 0x00, 0x11, 0xff, 0xff, 0xff, 0xff, 0xf0, 0x1a, 0x00, 0x0b, 0xff, 0xff, 0xff, 0xff, 0xf0, 
  0x0c, 0x00, 0x06, 0x00, 0x00, 0x00, 0x00, 0x00, 0x06, 0x00, 0x0c, 0x00, 0x00, 0x07, 0xff, 0x80, 
  0x03, 0x00, 0x18, 0x00, 0x00, 0x03, 0xcf, 0x00, 0x00, 0xe0, 0xe0, 0x00, 0x00, 0x01, 0x86, 0x00, 
  0x00, 0x3f, 0x80, 0x00, 0x00, 0x00, 0x00, 0x00, 0x00, 0x00, 0x00, 0x00, 0x00, 0x00, 0x00, 0x00, 
  0x00, 0x00, 0x00, 0x00, 0x00, 0x00, 0x00, 0x00
};

// Text to put beside logo - maximum 3 lines of 10 chars.
const PROGMEM char BANNER_LINE_0[] = "Train";
const PROGMEM char BANNER_LINE_1[] = "Movement";
const PROGMEM char BANNER_LINE_2[] = "Measurer";
const PROGMEM char *const BANNER_LINES[] = {BANNER_LINE_0, BANNER_LINE_1, BANNER_LINE_2};


// Defines for velocity bars
const PROGMEM byte velocityBar[LEDS_COUNT * 4] = {
  // velocity, red, green, blue
  0,   0, 255, 0,
  20,  0, 255, 0,
  40,  0, 255, 0,
  60,  0, 255, 255,
  80,  0, 255, 255,
  100, 255, 255, 0,
  120, 255, 255, 0,
  140, 255, 0, 0
};


/* Use test LEDs mode.
 * Line 1: The current test and stage of the test:
 *          - Scrolling and the number of white LEDs before the red one
 *          - Brightning and the brightness
 * Line 3: LED Strip pin, count, brightness
 * The LEDs first show Red, Green, Blue, Yellow, Magenta, Cyan with the rest White
 * this scrolls off the end of the strip. You then get Black, Red, Green, Blue, Yellow,
 * Magenta, Cyan, White and the rest Black with the brightness changing.
 * If the colours are wrong then you'll need to adjust the line #define LEDS_ORDER RGB
*/
//#define TEST_LEDS

/* Use test triggers mode.
 * Line 1:  Distance 0 and Distance 1
 * Line 2:  LED control pin and constant/frequency of IR LEDs (if light gates are being used)
 * Line 3:  triggers 0, .. n pins (black on white = input blocked, white on black = input unblocked)
 * LED 0:   Trigger 0 state (green = never blocked, red = blocked, blue = unblocked (but previously has been))
 * LED 1:   Trigger 1 state (green = never blocked, red = blocked, blue = unblocked (but previously has been))
 * LED 2:   Trigger 2 state (green = never blocked, red = blocked, blue = unblocked (but previously has been))
 * LED 3:   Trigger 3 state (green = never blocked, red = blocked, blue = unblocked (but previously has been))
 * LED 4:
 * LED 5:
 * LED 6+7: Direction determination
*/
//#define TEST_TRIGGERS


/* Pins used:
 *  Digital 0:  Serial RX
 *  Digital 1:  Serial TX
 *  Digital 2:  TRIGGER_3_PIN
 *  Digital 3:  TRIGGER_2_PIN
 *  Digital 4:  TRIGGER_1_PIN
 *  Digital 5:  TRIGGER_0_PIN
 *  Digital 6:  
 *  Digital 7:  
 *  Digital 8:  software uartable
 *  Digital 9:  software uartable
 *  Digital 10: 
 *  Digital 11: Light gates LEDs
 *  Digital 12: LED Stick
 *  Digital 13: LED_BUILTIN
 *  Analog  0:  
 *  Analog  1:  
 *  Analog  2:  
 *  Analog  3:  
 *  Analog  4:  I2C Data
 *  Analog  5:  I2C Clock
 *  Analog  6:  
 *  Analog  7:  
 */

// Setup screen
#if SCREEN_HEIGHT >= 64
  #define SCREEN_LINE_0 (SCREEN_HEIGHT - (4 * SCREEN_CHAR_HEIGHT))  // Pixel position for top of 1st line at text size 1
#else
  #define SCREEN_LINE_0 0                                           // Pixel position for top of 1st line at text size 1
#endif
#define SCREEN_LINE_1 (SCREEN_LINE_0 + SCREEN_CHAR_HEIGHT)          // Pixel position for top of 2nd line at text size 1
#define SCREEN_LINE_2 (SCREEN_LINE_1 + SCREEN_CHAR_HEIGHT)          // Pixel position for top of 3rd line at text size 1
#define SCREEN_LINE_3 (SCREEN_LINE_2 + SCREEN_CHAR_HEIGHT)          // Pixel position for top of 4th line at text size 1

#if SCREEN_ROTATION == 1 || SCREEN_ROTATION == 3
  Adafruit_SSD1306 display(SCREEN_HEIGHT, SCREEN_WIDTH, &Wire, SCREEN_RESET_PIN);
#else
  Adafruit_SSD1306 display(SCREEN_WIDTH, SCREEN_HEIGHT, &Wire, SCREEN_RESET_PIN);
#endif

// Setup LEDs
#ifdef LEDS_REVERSE
  #define LED_INDEX(i) (i)
  #define LED_RINDEX(i) (LEDS_COUNT - (i) - 1)
#else
  #define LED_INDEX(i) (LEDS_COUNT - (i) - 1)
  #define LED_RINDEX(i) (i)
#endif


// Final check of settings above
#if DISTANCE_0 < 1
  #error "DISTANCE_0 must be at least 1"
#endif
#if (!defined(VELOCITY_ONLY) || defined(TRIGGER_BLOCKS)) && DISTANCE_1 < 1 // required if using blocks or measuring acceleration
  #error "DISTANCE_1 must be at least 1"
#endif
#if !defined(TRIGGER_GATES) && !defined(TRIGGER_BLOCKS)
  #error "Either TRIGGER_GATES or TRIGGER_BLOCKS must be defined"
#endif
#if defined(TRIGGER_GATES) && defined(TRIGGER_BLOCKS)
  #error "Only one of TRIGGER_GATES or TRIGGER_BLOCKS may be defined"
#endif
#if LEDS_COUNT < 8
  #error "There must be at least 8 addressable LEDs connected"
#endif
#if SCREEN_WIDTH < 64
  #error "Screen must be at least 64 pixels wide"
#endif
#if SCREEN_HEIGHT < 32
  #error "Screen must be at least 32 pixels high"
#endif
#if !defined(GATE_LED_RATE) && GATE_LED_RATE != 0
  #if GATE_LED_RATE < 62
    #error "Light Gate LED frequency must be above 62Hz"
  #endif
  #if GATE_LED_RATE > 500000
    #error "Light Gate LED frequency must be below 500KHz"
  #endif
#endif


void setup()  {
  pinMode(LED_BUILTIN, OUTPUT);
  digitalWrite(LED_BUILTIN, HIGH);

  Serial.begin(9600, SERIAL_8N1);
  FastLED.addLeds<LEDS_TYPE, LEDS_PIN, LEDS_ORDER>(leds, LEDS_COUNT);
  FastLED.clear();
  FastLED.setBrightness(LEDS_BRIGHT);
  FastLED.show();

  // SSD1306_SWITCHCAPVCC = generate display voltage from 3.3V internally
  if(!display.begin(SSD1306_SWITCHCAPVCC, SCREEN_I2C_ADDRESS)) {
    Serial.println(F("ERROR: SSD1306 allocation failed."));
  }
  display.setRotation(SCREEN_ROTATION);
  display.clearDisplay();
  display.setTextColor(SSD1306_WHITE, SSD1306_BLACK);
  display.setTextWrap(false);
  display.drawBitmap((SCREEN_WIDTH - LOGO_WIDTH)/2, (SCREEN_HEIGHT - LOGO_HEIGHT)/2, logoBmp, LOGO_WIDTH, LOGO_HEIGHT, SSD1306_WHITE);
  display.display();

  extraSetup();

  Serial.print(F("READY: SCALE:1:"));
  Serial.print(SCALE);
  Serial.print(F(" DISTANCE_0:"));
  Serial.print(DISTANCE_0);
  Serial.print(F("mm DISTANCE_1:"));
  Serial.print(DISTANCE_1);
  Serial.print(F("mm INTER_TRAIN_DELAY:"));
  Serial.print(INTER_TRAIN_DELAY);
  #ifdef VELOCITY_ONLY
    Serial.print(F("ms MEASURING:VELOCITY"));
  #else
    Serial.print(F("ms MEASURING:ACCELERATION_VELOCITY"));
  #endif
  Serial.print(F(" TRIGGERS:"));
  Serial.print(TRIGGER_COUNT);
  #ifdef TRIGGER_GATES
    Serial.print(F("_GATES"));
  #endif
  #ifdef TRIGGER_BLOCKS
    Serial.print(F("_BLOCKS"));
  #endif
  Serial.println();

  afterSetupAnimation();
  digitalWrite(LED_BUILTIN, LOW);
}

void loop() {
  #ifdef TEST_LEDS
    testLeds();
  #endif
  #ifdef TEST_TRIGGERS
    testTriggers();
  #endif

  #ifdef VELOCITY_ONLY
    doVelocity();
  #else
    doVelocityAcceleration();
  #endif
}

void testLeds() {
  Serial.println(F("STATUS: Testing LEDs."));

  // Maximum width of 64 (10 characters)
  const unsigned int col0 = 0;
  const unsigned int col1 = SCREEN_WIDTH / 3;
  const unsigned int col2 = col1 + col1;
  const byte brightnesses[] = {1, 2, 4, 8, 16, 24, 32, 64, 96, 128, 192, 255};

  display.setTextSize(1);
  FastLED.clear();

  // Dispaly line 0: Title
  display.fillRect(0, SCREEN_LINE_0, SCREEN_WIDTH, SCREEN_CHAR_HEIGHT, SSD1306_WHITE);
  display.setCursor((SCREEN_WIDTH - (SCREEN_CHAR_WIDTH * 9)) / 2, SCREEN_LINE_0);
  display.setTextColor(SSD1306_BLACK, SSD1306_WHITE);
  display.print(F("TEST LEDs"));
  display.setTextColor(SSD1306_WHITE, SSD1306_BLACK);

  // Display line 3: LED Strip pin, count and brightness
  display.setCursor(col0, SCREEN_LINE_3);
  display.print(LEDS_PIN);
  display.setCursor(col1, SCREEN_LINE_3);
  display.print(LEDS_COUNT);
  display.setCursor(col2, SCREEN_LINE_3);
  display.print(LEDS_BRIGHT);

  display.display();

  while(true) {
    display.setCursor(col0, SCREEN_LINE_1);
    display.print(F("Scrolling      "));
    FastLED.setBrightness(LEDS_BRIGHT);
    for(int i = 0; i <= LEDS_COUNT; i++) {
      display.setCursor(66, SCREEN_LINE_1);
      display.print(i);
      display.display();
      for(int j = 0; j < i; j++) {leds[LED_INDEX(j)] = CRGB::White;}
      if(i < LEDS_COUNT - 0) {leds[LED_INDEX(i + 0)] = CRGB::Red;}
      if(i < LEDS_COUNT - 1) {leds[LED_INDEX(i + 1)] = CRGB::Green;}
      if(i < LEDS_COUNT - 2) {leds[LED_INDEX(i + 2)] = CRGB::Blue;}
      if(i < LEDS_COUNT - 3) {leds[LED_INDEX(i + 3)] = CRGB::Yellow;}
      if(i < LEDS_COUNT - 4) {leds[LED_INDEX(i + 4)] = CRGB::Magenta;}
      if(i < LEDS_COUNT - 5) {leds[LED_INDEX(i + 5)] = CRGB::Cyan;}
      for(int j = i + 6; j < LEDS_COUNT; j++) {leds[LED_INDEX(j)] = CRGB::White;}
      FastLED.show();
      delay(500);
    }

    display.setCursor(col0, SCREEN_LINE_1);
    display.print(F("Brightning     "));
    for(int i = 0; i < 12; i++) {
      display.setCursor(66, SCREEN_LINE_1);
      display.print(brightnesses[i]);
      display.display();
      FastLED.clear();
      FastLED.setBrightness(brightnesses[i]);
      leds[LED_INDEX(0)] = CRGB::Black;
      leds[LED_INDEX(1)] = CRGB::Red;
      leds[LED_INDEX(2)] = CRGB::Green;
      leds[LED_INDEX(3)] = CRGB::Blue;
      leds[LED_INDEX(4)] = CRGB::Yellow;
      leds[LED_INDEX(5)] = CRGB::Magenta;
      leds[LED_INDEX(6)] = CRGB::Cyan;
      leds[LED_INDEX(7)] = CRGB::White;
      FastLED.show();
      delay(750);      
    }
  }
}

void testTriggers() {
  Serial.println(F("STATUS: Testing triggers."));

  // Maximum width of 64 (10 characters)
  const unsigned int col0 = 0;
  const unsigned int col1 = SCREEN_WIDTH / 2;

  #ifdef TRIGGER_GATES
    irLeds(true);
  #endif
  display.setTextSize(1);
  FastLED.clear();

  // Display line 0: Title
  display.fillRect(0, SCREEN_LINE_0, SCREEN_WIDTH, SCREEN_CHAR_HEIGHT, SSD1306_WHITE);
  display.setCursor((SCREEN_WIDTH - (SCREEN_CHAR_WIDTH * 15)) / 2, SCREEN_LINE_0);
  display.setTextColor(SSD1306_BLACK, SSD1306_WHITE);
  display.print(F("TEST TRIGGERS"));
  display.setTextColor(SSD1306_WHITE, SSD1306_BLACK);

  // Display line 1: Distance 0->1 and 1->2
  display.setCursor(col0, SCREEN_LINE_1);
  display.print(DISTANCE_0);
  display.setCursor(col1, SCREEN_LINE_1);
  display.print(DISTANCE_1);

  // Display Line 2: Light gate IR LED pin constant/flash rate
  #ifdef TRIGGER_GATES
    #ifdef GATE_LED_PIN
      display.setCursor(col0, SCREEN_LINE_2);
      display.print(GATE_LED_PIN);
      display.setCursor(col1, SCREEN_LINE_2);
      #if GATE_LED_RATE == 0
        display.print(F("Constant"));
      #else
        display.print(GATE_LED_RATE / 1000.0);
        display.print(F("KHz"));
      #endif
    #else
      display.setCursor(col0, SCREEN_LINE_2);
      display.print(F("No LED control set."));
    #endif
  #endif

  boolean triggered[TRIGGER_COUNT] = {};  // Whether a given input has ever been triggered
  while(true) {
    // Display
    for(unsigned int i = 0; i < TRIGGER_COUNT; i++) {
      // Show pin number and state of trigger on the display
      if(triggerDetect(i)) {
        display.setTextColor(SSD1306_BLACK, SSD1306_WHITE);
      } else {
        display.setTextColor(SSD1306_WHITE, SSD1306_BLACK);
      }
      display.setTextSize(1);
      display.setCursor((col0 + (SCREEN_CHAR_WIDTH * (3 * i))), SCREEN_LINE_3);
      display.print(pgm_read_byte(TRIGGER_PINS + i));
    }

    // Show direction indication
    leds[LED_RINDEX(1)] = triggerDetect(0) ? CRGB::Magenta : CRGB::Black;
    leds[LED_RINDEX(0)] = triggerDetect(TRIGGER_COUNT - 1) ? CRGB::Magenta : CRGB::Black;

    // LEDs
    for(unsigned int i = 0; i < TRIGGER_COUNT; i++) {
      // Show current state of the light gate on LED strip
      if(triggerDetect(i)) {
        leds[LED_INDEX(TRIGGER_COUNT - 1 - i)] =  CRGB::Red;
        triggered[i] = true;
      } else {
        leds[LED_INDEX(TRIGGER_COUNT - 1 - i)] = triggered[i] ? CRGB::Blue : CRGB::Green;        
      }
    }
    display.display();
    FastLED.show();
  }
}
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

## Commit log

2020-06-11 Fix LICENSE.md's appearance in GitHub and add to arduino code file
    [TrainMovementMeasurer.ino]
2020-06-12 Make more use of PROGMEM
    Deals with shortage of dynamic memory starting to be a limiting factor.
    First symptom - having to limit the terminalError message length.
    [TrainMovementMeasurer.ino]
2020-06-13 Add control of light gate LED flash rate
2020-06-13 Add control of light gate LED pin

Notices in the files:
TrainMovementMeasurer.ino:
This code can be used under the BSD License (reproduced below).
